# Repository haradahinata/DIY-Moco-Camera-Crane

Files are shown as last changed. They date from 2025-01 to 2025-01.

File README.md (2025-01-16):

# DIY Moco Camera Crane

## 概要
**DIY Electric Camera Crane** は、個人や小規模な制作チームが手頃な価格で高品質な電動カメラクレーンを製作・使用できるようにすることを目的としたプロジェクトです。本プロジェクトでは、オープンソースの設計図やソースコードを提供し、必要な材料や手順を公開しています。

このプロジェクトの利点:
- **低コスト**: 制作コストを約20万円以内に抑えた設計。
- **カスタマイズ性**: 使用するカメラや撮影スペースに応じてサイズや仕様を調整可能。
- **オープンソース**: BlenderやTouchDesignerといった無料のソフトウェアで制御を実現。

---

## 特徴
- **フレーム構成**: 軽量かつ高剛性なアルミフレームを使用。
- **モーター制御**: 5軸のステッピングモーターでパン、チルト、上下、左右回転、フォーカスを制御。
- **Blender活用**: Pythonスクリプトを使用してリアルタイム制御と3D空間の同期を実現。
- **ゲームパッド操作**: 直感的な操作性を提供。
- **リアルタイム3D合成**: TouchDesignerとの連携でトラッキング機器不要の合成を可能に。

---

## 動作デモ
動作デモ

---

## 必要な材料・部品
- **フレーム**: アルミフレーム（カスタム長さ）
- **ステッピングモーター**: 5個
- **マイコン**: ESP32
- **ベアリング**: 耐荷重仕様の回転テーブル用ベアリング
- **ベルトおよびギア**: 3Dプリントパーツを含む
- **ソフトウェア**: Blender（無料）、TouchDesigner（無料版対応）

詳細な部品リストや購入リンクは [documentation](./docs/parts_list.md) を参照してください。

---

## プロジェクトファイル
リポジトリ内の`projects/`ディレクトリには、以下のプロジェクトファイルが含まれています。

- `blender/`: Blenderプロジェクトファイル（`camera_crane.blend`）
- `touchdesigner/`: TouchDesignerプロジェクトファイル（`crane_control.toe`）

これらのファイルは、クレーン制御のシミュレーションやリアルタイム3D合成に使用します。

---

## セットアップ手順
1. **フレームの組み立て**
   - 設計図に基づき、アルミフレームを組み立てます。

2. **モーターと配線**
   - ステッピングモーターをフレームに取り付け、ベルトで駆動系を構築します。
   - ESP32と各モーターを接続します。

3. **ソフトウェアのセットアップ**
   - Blenderでプロジェクトファイルを読み込みます。
   - TouchDesignerでプロジェクトファイルを読み込み、カメラ位置データをリアルタイムで受信可能にします。

4. **テストと調整**
   - Blenderで制御する仮想クレーンの動作と、現実のクレーンの同期を確認します。
   - 必要に応じてパラメータを調整します。

---

## 使用例
- 映画や動画撮影の特殊効果制作
- ライブ配信でのリアルタイム3D合成
- 低コストでの映像制作環境の構築

---

## ライセンス
このプロジェクトは [MIT License](./LICENSE) の下で公開されています。詳細についてはLICENSEファイルをご覧ください。

---

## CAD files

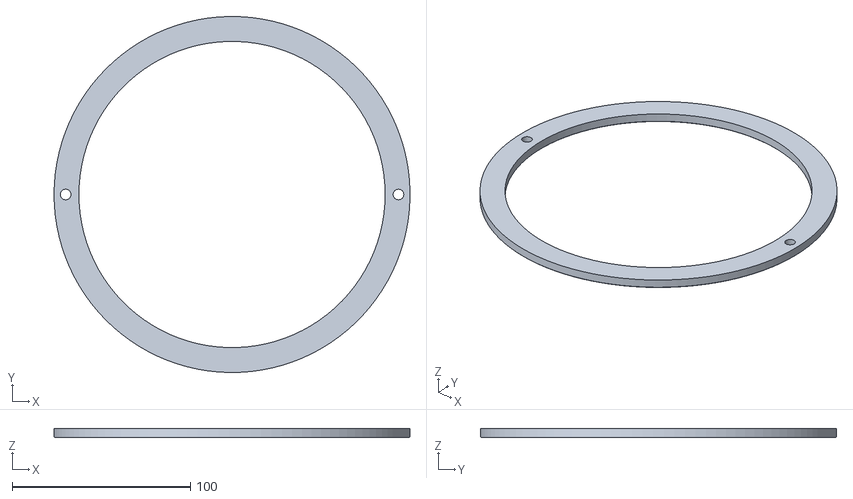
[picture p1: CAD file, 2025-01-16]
stl/spacer_202x6mm.stl
200.0 x 200.0 x 5.00

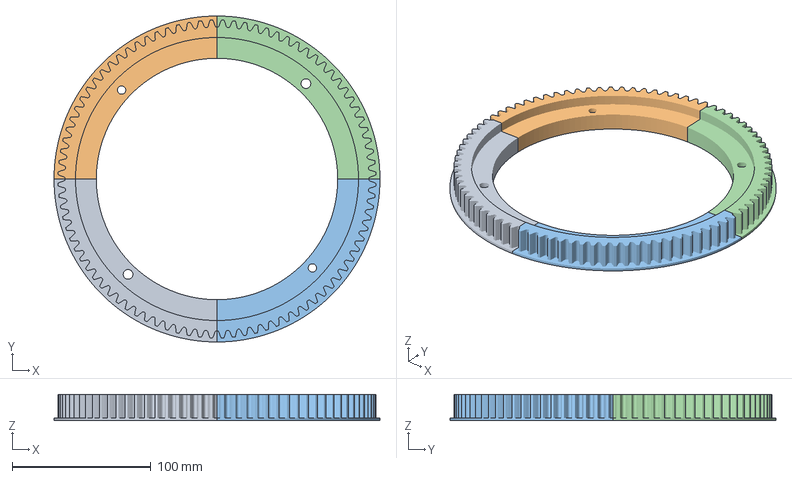
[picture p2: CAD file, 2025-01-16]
stl/gear_202mm_88t.3mf
235.0 x 235.0 x 19.0 mm
ボディ1
ボディ2
ボディ3
ボディ4

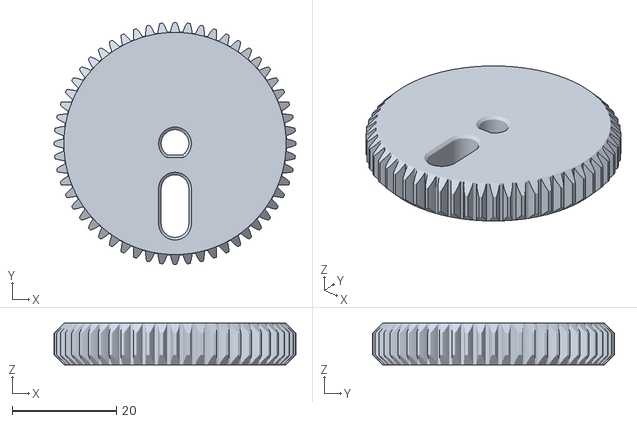
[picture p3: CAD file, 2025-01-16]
stl/focus_gear_56t.stl
46.4 x 46.4 x 8.00

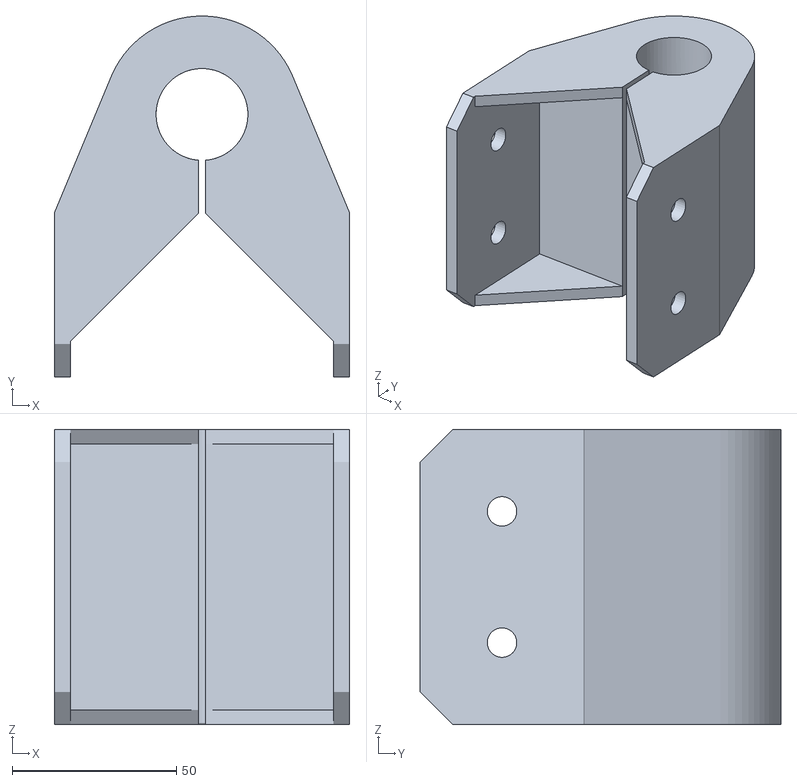
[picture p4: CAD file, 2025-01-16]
stl/weight_mount.stl
90.0 x 110.0 x 90.0

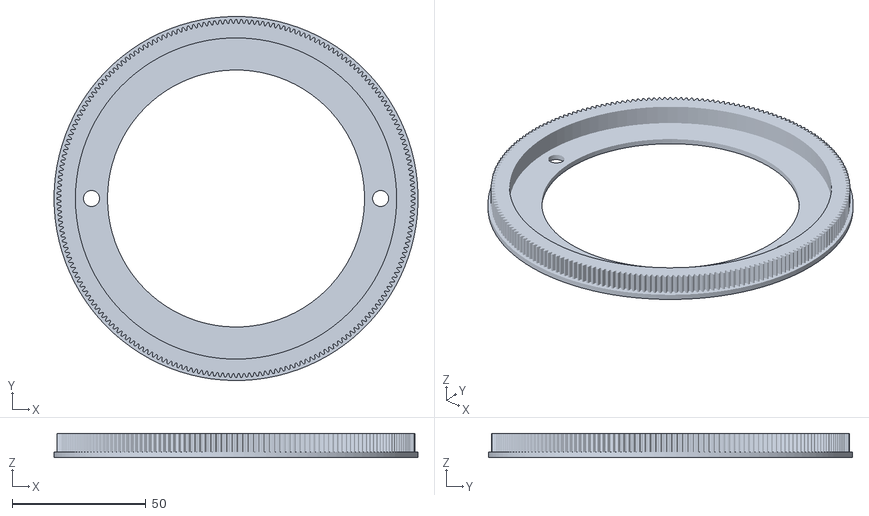
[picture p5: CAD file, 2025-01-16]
stl/gear_120mm_208t.stl
136.0 x 136.0 x 9.00

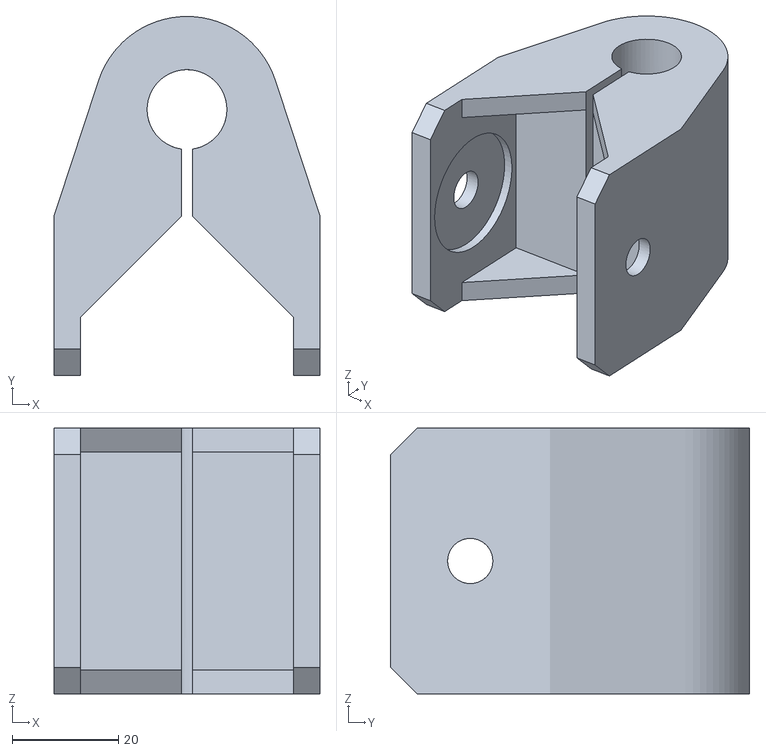
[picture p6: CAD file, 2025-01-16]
stl/subarm_mount.stl
50.0 x 67.5 x 50.0

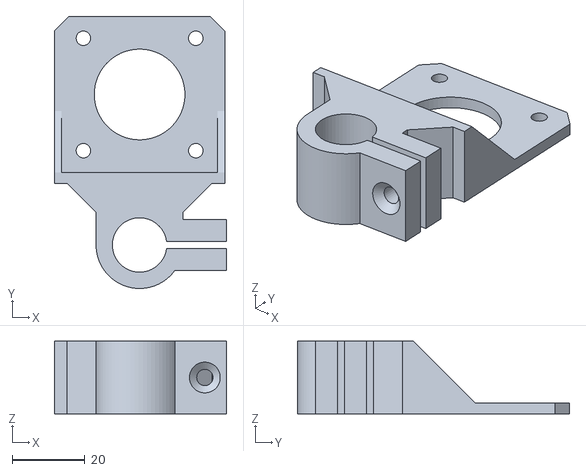
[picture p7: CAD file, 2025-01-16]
stl/focus_motor_mount.stl
47.5 x 75.0 x 20.0

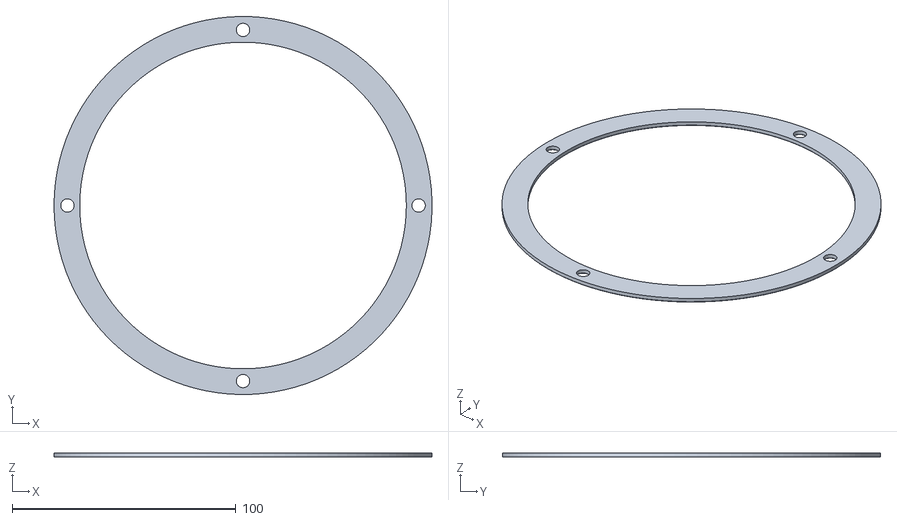
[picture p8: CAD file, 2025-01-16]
stl/spacer_202x2mm.stl
169.0 x 169.0 x 2.00

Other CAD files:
projects/blender/camera_crane.blend

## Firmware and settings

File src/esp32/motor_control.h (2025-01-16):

#include <AccelStepper.h>
#include <math.h>

// ピン設定
const int pulsePin1 = 22;   // モーター1のパルスピン
const int dirPin1   = 23;   // モーター1の方向ピン
const int pulsePin2 = 5;    // モーター2のパルスピン
const int dirPin2   = 18;   // モーター2の方向ピン
const int pulsePin3 = 16;   // モーター3のパルスピン
const int dirPin3   = 19;   // モーター3の方向ピン
const int pulsePin4 = 27;   // モーター4のパルスピン
const int dirPin4   = 25;   // モーター4の方向ピン
const int pulsePin5 = 15;   // モーター5のパルスピン
const int dirPin5   = 4;    // モーター5の方向ピン

AccelStepper stepper1(AccelStepper::DRIVER, pulsePin1, dirPin1);
AccelStepper stepper2(AccelStepper::DRIVER, pulsePin2, dirPin2);
AccelStepper stepper3(AccelStepper::DRIVER, pulsePin3, dirPin3);
AccelStepper stepper4(AccelStepper::DRIVER, pulsePin4, dirPin4);
AccelStepper stepper5(AccelStepper::DRIVER, pulsePin5, dirPin5);

// モーターの設定
const float microsteps1 = 12800.0f;    // モーター1のマイクロステップ数
const float gearRatio1 = 4.4f;         // モーター1のギア比
float stepsPerRevolution1;

const float microsteps2 = 12800.0f;    // モーター2のマイクロステップ数
const float gearRatio2 = 4.4f;         // モーター2のギア比
float stepsPerRevolution2;

const float microsteps3 = 1600.0f;     // モーター3のマイクロステップ数
const float gearRatio3 = 13.0f;        // モーター3のギア比
float stepsPerRevolution3;

const float microsteps4 = 1600.0f;     // モーター4のマイクロステップ数
const float gearRatio4 = 13.0f;        // モーター4のギア比
float stepsPerRevolution4;

const float microsteps5 = 1600.0f;     // モーター5のマイクロステップ数
const float gearRatio5 = 2.0f;         // モーター5のギア比
float stepsPerRevolution5;

// 各モーターの角度制限
const float minAngle1 = -180.0f;
const float maxAngle1 =  180.0f;

const float minAngle2 = -42.0f;
const float maxAngle2 =  42.0f;

const float minAngle3 = -120.0f;
const float maxAngle3 =  120.0f;

const float minAngle4 = -90.0f;
const float maxAngle4 =  90.0f;

const float minAngle5 =  0.0f;
const float maxAngle5 =  360.0f;

// プログラム開始時の角度
const float startAngle1 =  0.0f;
const float startAngle2 = -42.0f;
const float startAngle3 =  0.0f;
const float startAngle4 =  0.0f;
const float startAngle5 =  0.0f;

// ターゲットステップ数（目標位置）
float targetSteps1 = 0.0f;
float targetSteps2 = 0.0f;
float targetSteps3 = 0.0f;
float targetSteps4 = 0.0f;
float targetSteps5 = 0.0f;

// 速度・加速度設定
const float maxSpeed  = 10000.0f;  // 最大速度
const float maxAccel  = 5000.0f;   // 最大加速度
const float minSpeed  = 100.0f;    // 最小速度
const float minAccel  = 50.0f;     // 最小加速度

void setup() {
  Serial.begin(115200);
  delay(1000);
  
  // 各モーターのstepsPerRevolutionを計算
  stepsPerRevolution1 = microsteps1 * gearRatio1;
  stepsPerRevolution2 = microsteps2 * gearRatio2;
  stepsPerRevolution3 = microsteps3 * gearRatio3;
  stepsPerRevolution4 = microsteps4 * gearRatio4;
  stepsPerRevolution5 = microsteps5 * gearRatio5;

  // 5つのステッピングモーターに対し、初期速度・加速度を設定
  stepper1.setMaxSpeed(maxSpeed);
  stepper1.setAcceleration(maxAccel);

  stepper2.setMaxSpeed(maxSpeed);
  stepper2.setAcceleration(maxAccel);

  stepper3.setMaxSpeed(maxSpeed);
  stepper3.setAcceleration(maxAccel);

  stepper4.setMaxSpeed(maxSpeed);
  stepper4.setAcceleration(maxAccel);

  stepper5.setMaxSpeed(maxSpeed);
  stepper5.setAcceleration(maxAccel);

  // モーター5を-360度回転させる
  long stepsToMove = -stepsPerRevolution5;
  stepper5.moveTo(stepsToMove);

  // モーター5が移動を完了するまで待機
  while (stepper5.distanceToGo() != 0) {
    stepper5.run();
  }

  // 開始時の位置を設定
  stepper1.setCurrentPosition((startAngle1 / 360.0f) * stepsPerRevolution1);
  stepper2.setCurrentPosition((startAngle2 / 360.0f) * stepsPerRevolution2);
  stepper3.setCurrentPosition((startAngle3 / 360.0f) * stepsPerRevolution3);
  stepper4.setCurrentPosition((startAngle4 / 360.0f) * stepsPerRevolution4);
  stepper5.setCurrentPosition((startAngle5 / 360.0f) * stepsPerRevolution5);
}

void loop() {
  if (Serial.available() > 0) {
    String input = Serial.readStringUntil('\n');

    if (input.startsWith("ANGLE:")) {
      // "ANGLE:" 以降を取り出して","区切りで5つの角度をパースする
      String anglesStr = input.substring(6);
      float angles[5];
      
      // 角度を取り出し
      for (int i = 0; i < 5; i++) {
        int commaIndex = anglesStr.indexOf(',');
        if (commaIndex == -1 && i < 4) {
          // 不足する角度があればデフォルト値（0）を設定
          angles[i] = 0.0f;
          break;
        }
        if (commaIndex == -1) {
          // 最後の角度
          angles[i] = anglesStr.toFloat();
        } else {
          // カンマまでの部分をfloat変換
          angles[i] = anglesStr.substring(0, commaIndex).toFloat();
          anglesStr = anglesStr.substring(commaIndex + 1);
        }
      }

      // 前回のターゲットステップを保存
      float previousTargetSteps1 = targetSteps1;
      float previousTargetSteps2 = targetSteps2;
      float previousTargetSteps3 = targetSteps3;
      float previousTargetSteps4 = targetSteps4;
      float previousTargetSteps5 = targetSteps5;

      // 角度制限 & ターゲットステップ計算
      float angle1 = constrain(angles[0], minAngle1, maxAngle1);
      float angle2 = constrain(angles[1], minAngle2, maxAngle2);
      float angle3 = constrain(angles[2], minAngle3, maxAngle3);
      float angle4 = constrain(angles[3], minAngle4, maxAngle4);
      float angle5 = constrain(angles[4], minAngle5, maxAngle5);

      targetSteps1 = (angle1 / 360.0f) * stepsPerRevolution1;
      targetSteps2 = (angle2 / 360.0f) * stepsPerRevolution2;
      targetSteps3 = (angle3 / 360.0f) * stepsPerRevolution3;
      targetSteps4 = (angle4 / 360.0f) * stepsPerRevolution4;
      targetSteps5 = (angle5 / 360.0f) * stepsPerRevolution5;

      stepper1.moveTo(targetSteps1);
      stepper2.moveTo(targetSteps2);
      stepper3.moveTo(targetSteps3);
      stepper4.moveTo(targetSteps4);
      stepper5.moveTo(targetSteps5);

      
      // 目標位置が1つでも変化した場合のみ、速度と加速度を更新
      bool changed = (previousTargetSteps1 != targetSteps1) ||
                     (previousTargetSteps2 != targetSteps2) ||
                     (previousTargetSteps3 != targetSteps3) ||
                     (previousTargetSteps4 != targetSteps4) ||
                     (previousTargetSteps5 != targetSteps5);

      if (changed) {
        // 各モーターの移動距離を計算
        float distance1 = abs(targetSteps1 - stepper1.currentPosition());
        float distance2 = abs(targetSteps2 - stepper2.currentPosition());
        float distance3 = abs(targetSteps3 - stepper3.currentPosition());
        float distance4 = abs(targetSteps4 - stepper4.currentPosition());
        float distance5 = abs(targetSteps5 - stepper5.currentPosition());
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
